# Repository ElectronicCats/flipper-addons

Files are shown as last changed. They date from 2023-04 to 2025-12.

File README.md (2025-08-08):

# Electronic Cats Flipper Add-Ons 😼 :dolphin: 

This repository contains a collection of our Add-Ons for Flipper, the open-source hardware platform for hacking and security research.

<a href="https://github.com/ElectronicCats/flipper-addons/wiki">
  
  
</a>

<p align=center>
<a href="https://electroniccats.com/?s=flipper&post_type=product&product_cat=">
  
</a>
<a href="https://github.com/ElectronicCats/flipper-addons/wiki">
  
</a>
</p>

<p align=center>
    Also available at distributors:
  </p>
<p align=center>
  <a href="https://labs.ksec.co.uk/product-category/electronic-cat/">
    
  </a>
</p>

## Working
- Marauder Magspoof
- Marauder
- SubGHz LoRa ([**Flipper LoRa Relay App**](https://github.com/ElectronicCats/flipper-SX1262-LoRa))
- MagSpoof
- Modbus ([**Flipper RS485 ModBus App**](https://github.com/ElectronicCats/flipper-rs485modbus))
- CANBus ([**Flipper CANBUS App**](https://github.com/ElectronicCats/flipper-MCP2515-CANBUS))
- Ethernet ([**Flipper ENC28J60 Ethernet App**](https://github.com/ElectronicCats/flipper-ENC28J60-ethernet))
  
 ## Prototypes
- UWB

## How to contribute 
 Contributions are welcome! 

Please read the document [**Contribution Manual**](https://github.com/ElectronicCats/electroniccats-cla/blob/main/electroniccats-contribution-manual.md)  which will show you how to contribute your changes to the project.

✨ Thanks to all our [contributors](https://github.com/ElectronicCats/flipper-addons/graphs/contributors)! ✨

See [**_Electronic Cats CLA_**](https://github.com/ElectronicCats/electroniccats-cla/blob/main/electroniccats-cla.md) for more information.

See the  [**community code of conduct**](https://github.com/ElectronicCats/electroniccats-cla/blob/main/electroniccats-community-code-of-conduct.md) for a vision of the community we want to build and what we expect from it.

## Maintainer

<p align=center>
<a href="https://github.com/sponsors/ElectronicCats">
  
</a>
</p>

Electronic Cats invests time and resources providing this open-source design, please support Electronic Cats and open-source hardware by purchasing products from Electronic Cats!

## License

<a
href="https://github.com/ElectronicCats">



</a>

Designed by Electronic Cats.

Firmware released under an GNU AGPL v3.0 license. See the LICENSE file for more information.

Hardware released under an CERN Open Hardware Licence v1.2. See the LICENSE_HARDWARE file for more information.

Electronic Cats is a registered trademark, please do not use if you sell these PCBs.

Jul 2022

[Agregando el link como referencia]: <https://github.com/ElectronicCats/Template-Project-KiCAD-CI>

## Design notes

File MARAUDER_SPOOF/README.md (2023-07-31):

# Marauder Spoof
It is the mix of our famous Magspoof version with an ESP32S3 module loaded with Marauder A suite of WiFi/Bluetooth offensive and defensive tools for the ESP32

This addon adds the function of the famous Magspoof to Flipper, we use the same components and improvements that have our versions of magspoof, now adapted to Flipper. 

## How does MagSpoof work?
- Allows you to store all of your credit cards and magstripes in one device
- Works on traditional magstripe readers wirelessly (no NFC/RFID required)
- Can disable Chip-and-PIN (code not included)
- Correctly predicts Amex credit card numbers + expirations from previous card number (code not included)
- Supports all three magnetic stripe tracks, and even supports Track 1+2 simultaneously
- Easy to build using Arduino or other common parts
- MagSpoof can be used as a traditional credit card and simply store all of your credit cards (and with modification, can technically disable chip requirements) in various impressive and exciting form factors, or can be used for security research in any area that would traditionally require a magstripe, such as readers for credit cards, drivers licenses, hotel room keys, automated parking lot tickets, etc.

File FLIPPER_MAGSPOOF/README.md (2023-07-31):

# Flipper Magspoof
This addon adds the function of the famous Magspoof to Flipper, we use the same components and improvements that have our versions of magspoof, now adapted to Flipper. 

Flipper Magspoof is a device that can spoof/emulate any magnetic stripe or credit card. It can work “wirelessly”, even on standard magstripe/credit card readers, by generating a strong electromagnetic field that emulates a traditional magnetic stripe card.

### How does MagSpoof work?
- Allows you to store all of your credit cards and magstripes in one device
- Works on traditional magstripe readers wirelessly (no NFC/RFID required)
- Can disable Chip-and-PIN (code not included)
- Correctly predicts Amex credit card numbers + expirations from previous card number (code not included)
- Supports all three magnetic stripe tracks, and even supports Track 1+2 simultaneously
- Easy to build using Arduino or other common parts
- MagSpoof can be used as a traditional credit card and simply store all of your credit cards (and with modification, can technically disable chip requirements) in various impressive and exciting form factors, or can be used for security research in any area that would traditionally require a magstripe, such as readers for credit cards, drivers licenses, hotel room keys, automated parking lot tickets, etc.

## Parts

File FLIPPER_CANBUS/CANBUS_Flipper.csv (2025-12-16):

Value | Reference | Footprint | LCSC# | Qty | DNP | manf#
10uF | C1,C9,C10 | Capacitor_SMD:C_0603_1608Metric | C19702 | 3
18pF | C2,C3 | Capacitor_SMD:C_0603_1608Metric | C5137620 | 2
0.1uF | C4,C5,C11 | Capacitor_SMD:C_0603_1608Metric | C14663 | 3
4.7nF | C6 | Capacitor_SMD:C_0603_1608Metric | C85980 | 1
47pF | C7,C8 | Capacitor_SMD:C_0603_1608Metric | C5137501 | 2
MMBZ27VCL-7-F | D1,D2 | Package_TO_SOT_SMD:SOT-23 | C698227 | 2
Conn_01x08_Socket | J1 | Connector_PinHeader_2.54mm:PinHeader_1x08_P2.54mm_Vertical | C7501586 | 1
Conn_01x10_Socket | J2 | Connector_PinHeader_2.54mm:PinHeader_1x10_P2.54mm_Vertical | C7430366 | 1
Conn | J3 | TerminalBlock:TerminalBlock_bornier-2_P5.08mm |  | 1 |  | TRT-02
STBY SEL | JP1 | Footprints:Jumper | C163836 | 1
STBY | JP2 | Footprints:Jumper | C163836 | 1
Jumper_2_Open | JP3 | Jumper:SolderJumper-2_P1.3mm_Open_Pad1.0x1.5mm |  | 1 | DNP
10K | R1 | Resistor_SMD:R_0603_1608Metric | C217281 | 1
60.2 | R2,R5 | Resistor_SMD:R_0603_1608Metric | C2086358 | 2
MCP251863T-H-SS | U3 | Package_SO:SSOP-28_5.3x10.2mm_P0.65mm | C5226885 | 1
40MHz | Y1 | Crystal:Crystal_SMD_EuroQuartz_MT-4Pin_3.2x2.5mm | C1985459 | 1

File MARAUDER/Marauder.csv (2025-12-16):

Reference | Qty | Value | DNP | Footprint | Datasheet | LCSC# | manf#
C1,C2 | 2 | 10uF |  | Capacitor_SMD:C_0603_1608Metric |  | C85713
C3,C4,C5 | 3 | 100nF |  | Capacitor_SMD:C_0603_1608Metric |  | C597251
J1 | 1 | Conn_01x08_Socket |  | Connector_PinHeader_2.54mm:PinHeader_1x08_P2.54mm_Vertical | ~ | C492407
J2 | 1 | Conn_01x08_Socket | DNP | Connector_PinHeader_2.54mm:PinHeader_1x08_P2.54mm_Vertical | ~ | C492407
J3 | 1 | Conn_01x10_Socket |  | Connector_PinHeader_2.54mm:PinHeader_1x10_P2.54mm_Vertical | ~ | C57369
J4 | 1 | GPS | DNP | Connector_PinHeader_2.54mm:PinHeader_1x05_P2.54mm_Vertical | ~
J5 | 1 | Conn_01x10_Socket | DNP | Connector_PinHeader_2.54mm:PinHeader_1x10_P2.54mm_Vertical | ~ | C57369
P1 | 1 | USB_C_Plug_USB2.0 |  | Connectors:C393939 | https://datasheet.lcsc.com/lcsc/2108132030_Korean-Hroparts-Elec-TYPE-C-31-M-31_C2760486.pdf | C2760486
Q1,Q2 | 2 | DMP2004TK-7 |  | Package_TO_SOT_SMD:SOT-523 | ~ |  | DMP2004TK-7
R1,R2,R7 | 3 | 10K |  | Resistor_SMD:R_0603_1608Metric |  | C217281
R3,R4 | 2 | 5k1 |  | Resistor_SMD:R_0603_1608Metric | https://datasheet.lcsc.com/lcsc/1810170519_PANASONIC-ERJ3RBD5101V_C191782.pdf | C156350
R6 | 1 | 150 |  | Resistor_SMD:R_0603_1608Metric | ~ | C2692872
R8,R9 | 2 | 4k7 |  | Resistor_SMD:R_0603_1608Metric | ~ | C394547
SW1 | 1 | RESET |  | Button_Switch_SMD:SW_SPST_TL3342 | https://datasheet.lcsc.com/lcsc/2205161616_E-Switch-TL3342F450QG_C2886897.pdf | C2886897 | TL3342F450QG
SW2 | 1 | GPIO |  | Button_Switch_SMD:SW_SPST_TL3342 | https://datasheet.lcsc.com/lcsc/2205161616_E-Switch-TL3342F450QG_C2886897.pdf | C2886897 | TL3342F450QG
U1 | 1 | ESP32-C5-WROOM-1-N4 |  | Marauder:XCVR_ESP32-C5-WROOM-1U-N8R8 |  |  | 356-ESP32C5WROM1N4

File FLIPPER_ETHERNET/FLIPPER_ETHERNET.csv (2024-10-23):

Reference | Value | Datasheet | Footprint | Qty | DNP | #LSCS | Proveedor | manf#
C1,C5 | 18pF |  | Capacitor_SMD:C_0603_1608Metric | 2 |  | C107040 | LCSC | CC0603JRNPO9BN180
C2 | 10uF |  | Capacitor_SMD:C_0603_1608Metric | 1 |  | C1691 | LCSC | CL10A106MQ8NNNC
C3,C4,C6,C7,C8,C9,C10 | 0.1uF | ~ | Capacitor_SMD:C_0603_1608Metric | 7 |  | C14663 | LCSC | CC0603KRX7R9BB104
FB1 | FerriteBead 80 mA | https://www.lcsc.com/datasheet/lcsc_datasheet_2312131724_Vishay-Intertech-ILBB0805ER202V_C6639322.pdf | FLIPPER_ETHERNET:BLM18SP221SN1B | 1 |  | C85824 | LCSC | BLM18AG102SN1D
J1 | RJ45_Hanrun_HR911105A_Horizontal | https://www.lcsc.com/datasheet/lcsc_datasheet_1811141815_HANRUN-Zhongshan-HanRun-Elec-HR911105A_C12074.pdf | Connector_RJ:RJ45_Hanrun_HR911105A_Horizontal | 1 |  | C12074 | LCSC | HR911105A
J2 | Conn_01x08_Socket | ~ | Connector_PinHeader_2.54mm:PinHeader_1x08_P2.54mm_Vertical | 1 |  | C7501586 | LCSC | PH2.54-01-08PZD
J3 | Conn_01x10_Socket | ~ | Connector_PinHeader_2.54mm:PinHeader_1x10_P2.54mm_Vertical | 1 |  | C7501587 | LCSC | PH2.54-01-10PZD
R1 | 100R | ~ | Resistor_SMD:R_0603_1608Metric | 1 |  | C22775 | LCSC | 0603WAF1000T5E
R2 | 10K | ~ | Resistor_SMD:R_0603_1608Metric | 1 |  | C2930027 | LCSC | FRC0603J103TS
R5,R6,R7,R8 | 49.9R |  | Resistor_SMD:R_0603_1608Metric | 4 |  | C23185 | LCSC | 0603WAF499JT5E
R9 | 2.32K |  | Resistor_SMD:R_0603_1608Metric | 1 |  | C2933173 | LCSC | FRC0603F2321TS
R12,R13 | 51R | ~ | Resistor_SMD:R_0603_1608Metric | 2 |  | C23197 | LCSC | 0603WAF510JT5E
SW1 | SW_Push | ~ | Button_Switch_SMD:SW_Push_1P1T_XKB_TS-1187A | 1 |  | C2886897 | LCSC | TS-1187A-C-C-B
U1 | ENC28J60x-ML | https://ww1.microchip.com/downloads/aemDocuments/documents/OTH/ProductDocuments/DataSheets/39662e.pdf | Package_DFN_QFN:QFN-28-1EP_6x6mm_P0.65mm_EP4.25x4.25mm | 1 |  | C57281 | Mouser | ENC28J60-I/ML
Y1 | 25MHz | https://www.lcsc.com/datasheet/lcsc_datasheet_2304140030_JGHC-S2125000101080_C390792.pdf | Crystal:Crystal_SMD_SeikoEpson_FA128-4Pin_2.0x1.6mm | 1 |  | C390792 | LCSC | S2125000101080

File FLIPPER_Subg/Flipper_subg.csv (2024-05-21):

# | Reference | Qty | Value | Footprint | DNP | LCSC# | manf#
1 | AE1, AE2 | 2 | Antenna | RF_Antenna:Texas_SWRA416_868MHz_915MHz | DNP | - | -
2 | AE3 | 1 | Antenna_Shield | subg:CONN1_U.FL-R-SMT-180_HIR |  | C411563
3 | AE4 | 1 | u.fl | subg:CONN1_U.FL-R-SMT-180_HIR |  | C411563
4 | C1, C2, C5, C8, C9, C10 | 6 | 0.1uF | Capacitor_SMD:C_0603_1608Metric |  | C14663 | CC0603KRX7R9BB104
5 | C3, C6 | 2 | 27pF | Capacitor_SMD:C_0603_1608Metric |  | C92670 | 0603YA270KAT2A
6 | C4 | 1 | 470nF | Capacitor_SMD:C_0603_1608Metric |  | C170149 | CL10A474KB8NNNC
7 | C7 | 1 | 47pF | Capacitor_SMD:C_0603_1608Metric |  | C519486 | CC0603FRNPO9BN470
8 | C11 | 1 | 10uF | Capacitor_SMD:C_0603_1608Metric |  | C85713
9 | C12, C14 | 2 | 1nF | Capacitor_SMD:C_0603_1608Metric |  | C1588 | CL10B102KB8NNNC
10 | C13 | 1 | 100pF | Capacitor_SMD:C_0603_1608Metric |  | C14858 | CL10C101JB8NNNC
11 | C15, C16 | 2 | 3.3pF | Capacitor_SMD:C_0603_1608Metric |  | C2909455
12 | D1 | 1 | LED | LED_SMD:LED_0805_2012Metric |  | C205442 | ORH-G35A
13 | J1 | 1 | Conn_01x10_Socket | Connector_PinHeader_2.54mm:PinHeader_1x10_P2.54mm_Vertical |  | C492418
14 | J2 | 1 | Conn_01x08_Socket | Connector_PinHeader_2.54mm:PinHeader_1x08_P2.54mm_Vertical |  | C2894950
15 | L1 | 1 | 15uH | Inductor_SMD:L_0603_1608Metric |  | C57838 | SDFL1608T150KTF
16 | L2 | 1 | 47nH | Inductor_SMD:L_0603_1608Metric |  | C29683 | SCHF160808H47NJT
17 | L3 | 1 | 9.1nH | Inductor_SMD:L_0603_1608Metric |  | C395094 | VHF160808H9N1JT
18 | R1 | 1 | 56K | Resistor_SMD:R_0603_1608Metric |  | C2828642
19 | R2, R4 | 2 | 100R | Resistor_SMD:R_0603_1608Metric |  | C700506 | RT0603DRD07100RL
20 | R3 | 1 | 1K | Resistor_SMD:R_0805_2012Metric |  | C25623 | 0805W8J0102T5E
21 | R5, R7 | 2 | 0 | Resistor_SMD:R_0402_1005Metric |  | C140225
22 | R6, R8 | 2 | 0 | Resistor_SMD:R_0402_1005Metric | DNP | C140225
23 | U1 | 1 | SX1262IMLTRT | Package_DFN_QFN:QFN-24-1EP_4x4mm_P0.5mm_EP2.65x2.65mm |  | C191341
24 | U2 | 1 | CC1101RGPR | Package_DFN_QFN:QFN-20-1EP_4x4mm_P0.5mm_EP2.5x2.5mm_ThermalVias |  | C29953
25 | U3 | 1 | 0900FM15D0039 | subg:0900FM15D0039E |  |  | 0900FM15D0039E
26 | U4 | 1 | 0915BM15A0001E | subg:0915BM15A0001E |  |  | 0915BM15A0001E
27 | U5 | 1 | PE42421 | Package_TO_SOT_SMD:SOT-363_SC-70-6 |  |  | PE42421SCAA-Z
28 | Y1 | 1 | 32Mhz | Crystal:Crystal_SMD_2520-4Pin_2.5x2.0mm |  | C255969 | Q24FA20H0021700
29 | Y2 | 1 | 26Mhz | Crystal:Crystal_SMD_2520-4Pin_2.5x2.0mm |  |  | ECS-260-8-36-CKY-TR

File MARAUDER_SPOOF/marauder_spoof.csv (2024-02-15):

Reference | Value | Footprint | Datasheet | LCSC# | manf# | provedor | Qty
C1 | 1uF | Capacitor_SMD:C_0603_1608Metric | https://datasheet.lcsc.com/lcsc/1912111437_CCTC-TCC0603COG100J500CT_C376764.pdf | C15849 |  | LCSC | 1
C2-C4 | 10uF | Capacitor_SMD:C_0603_1608Metric | https://datasheet.lcsc.com/lcsc/1912111437_CCTC-TCC0603COG100J500CT_C376764.pdf | C85713 |  | LCSC | 3
J1 | Coil | Connector_PinHeader_2.54mm:PinHeader_1x02_P2.54mm_Vertical | ~ |  | WR301025-19M8-G |  | 1
J2 | Conn_01x10_Socket | Connector_PinHeader_2.54mm:PinHeader_1x10_P2.54mm_Vertical | ~ | C57369 |  |  | 1
J3 | Conn_01x08_Socket | Connector_PinHeader_2.54mm:PinHeader_1x08_P2.54mm_Vertical | ~ | C492407 |  |  | 1
J6 | GPS | Connector_PinHeader_2.54mm:PinHeader_1x05_P2.54mm_Vertical | ~ |  |  |  | 1
P1 | USB_C_Plug_USB2.0 | Connectors:C393939 | https://datasheet.lcsc.com/lcsc/2108132030_Korean-Hroparts-Elec-TYPE-C-31-M-31_C2760486.pdf | C2760486 |  | LCSC | 1
Q1, Q2 | DMP2004TK-7 | Package_TO_SOT_SMD:SOT-523 | ~ |  | DMP2004TK-7 | MOUSER | 2
R1, R2, R5, R6 | 10K | Resistor_SMD:R_0603_1608Metric | -- mixed values -- | C2930027 |  | LCSC | 4
R3, R4 | 5k1 | Resistor_SMD:R_0603_1608Metric | https://datasheet.lcsc.com/lcsc/1810170519_PANASONIC-ERJ3RBD5101V_C191782.pdf | C156350 |  | LCSC | 2
R7 | 150 | Resistor_SMD:R_0603_1608Metric | ~ | C2692872 |  | LCSC | 1
R8, R9 | 4k7 | Resistor_SMD:R_0603_1608Metric | ~ | C394547 |  | LCSC | 2
SW1 | RESET | Button_Switch_SMD:SW_SPST_TL3342 | https://datasheet.lcsc.com/lcsc/2205161616_E-Switch-TL3342F450QG_C2886897.pdf |  | TL3342F450QG | LCSC | 1
SW2 | GPIO | Button_Switch_SMD:SW_SPST_TL3342 | https://datasheet.lcsc.com/lcsc/2205161616_E-Switch-TL3342F450QG_C2886897.pdf |  | TL3342F450QG | LCSC | 1
U1 | TC4424 | Package_SO:SOIC-8_3.9x4.9mm_P1.27mm | https://www.mouser.mx/datasheet/2/268/21998b-53545.pdf | C44150 |  |  | 1
U2 | ESP32-S3-WROOM-1U-N4 | RF_Module:ESP32-S3-WROOM-1U | https://www.espressif.com/sites/default/files/documentation/esp32-s3-wroom-1_wroom-1u_datasheet_en.pdf |  | ESP32-S3-WROOM-1U-N4 | MOUSER | 1

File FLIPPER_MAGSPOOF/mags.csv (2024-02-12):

# | Reference | Qty | Value | Footprint | DNP | LCSC# | manf#
1 | J1 | 1 | Coil | Connector_PinHeader_2.54mm:PinHeader_1x02_P2.54mm_Vertical |  |  | WMRR138F-0
2 | J2 | 1 | Conn_01x10_Socket | Connector_PinHeader_2.54mm:PinHeader_1x10_P2.54mm_Horizontal |  | C57369
3 | J3 | 1 | Conn_01x08_Socket | Connector_PinHeader_2.54mm:PinHeader_1x08_P2.54mm_Horizontal |  | C492407
4 | J4 | 1 | Conn_01x08_Socket | Connector_PinHeader_2.54mm:PinHeader_1x08_P2.54mm_Vertical | DNP | C492407
5 | J5 | 1 | Conn_01x10_Socket | Connector_PinHeader_2.54mm:PinHeader_1x10_P2.54mm_Vertical | DNP | C57369
6 | SW1 | 1 | On | footprintsg:JS102011SAQN |  |  | JS102011SAQN
7 | U1 | 1 | TC4424 | Package_SO:SOIC-8_3.9x4.9mm_P1.27mm |  | C44150 | TC4424AVOA713

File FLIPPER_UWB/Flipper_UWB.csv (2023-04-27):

# | Reference | Qty | Value | Footprint | DNP | LCSC# | manf#
1 | C1 | 1 | 100uF | Capacitor_SMD:C_0805_2012Metric |  |  | 581-TLCR107M006RTA
2 | D1, D2 | 2 | LED | LED_SMD:LED_0805_2012Metric |  | C205442 | ORH-G35A
3 | D3 | 1 | LED | LED_SMD:LED_0805_2012Metric |  | C84261 | NCD0805Y1
4 | D4 | 1 | LED | LED_SMD:LED_0805_2012Metric |  | C130114 | D-R080508L3-KS2
5 | IC1 | 1 | DWM1000 | RF_Module:DWM1000 |  |  | 772-DWM1000
6 | J1 | 1 | Conn_01x08_Socket | Connector_PinHeader_2.54mm:PinHeader_1x08_P2.54mm_Horizontal |  | C5360907 | PZ2.54-1*20-WZ
7 | J2 | 1 | Conn_01x10_Socket | Connector_PinHeader_2.54mm:PinHeader_1x10_P2.54mm_Horizontal |  | C5360907 | PZ2.54-1*20-WZ
8 | R1, R2, R3, R4, R5 | 5 | 1K | Resistor_SMD:R_0805_2012Metric |  | C25623 | 0805W8J0102T5E

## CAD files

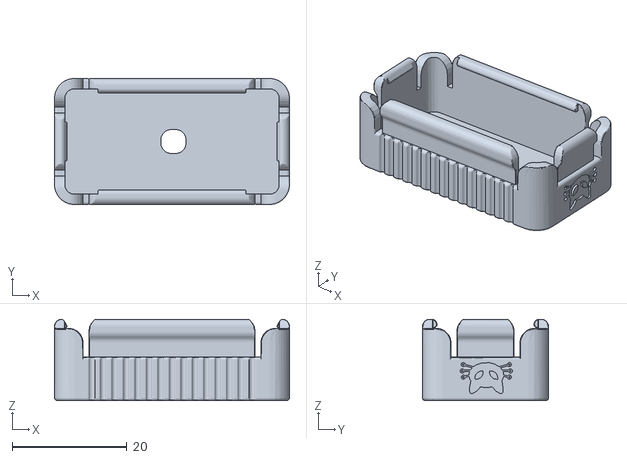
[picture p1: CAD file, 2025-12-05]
CASES/FLIPPER_CANBUS/OBD-PLUG-EC.stl
41.0 x 22.0 x 14.2

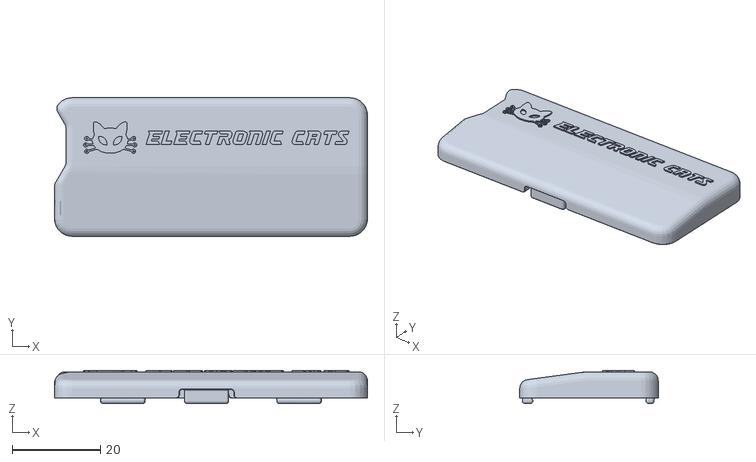
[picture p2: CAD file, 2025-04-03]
CASES/FLIPPER_MAGSPOOF/PART A-FLIPPER MAGSPOOF CASE.stl
71.0 x 31.5 x 7.50

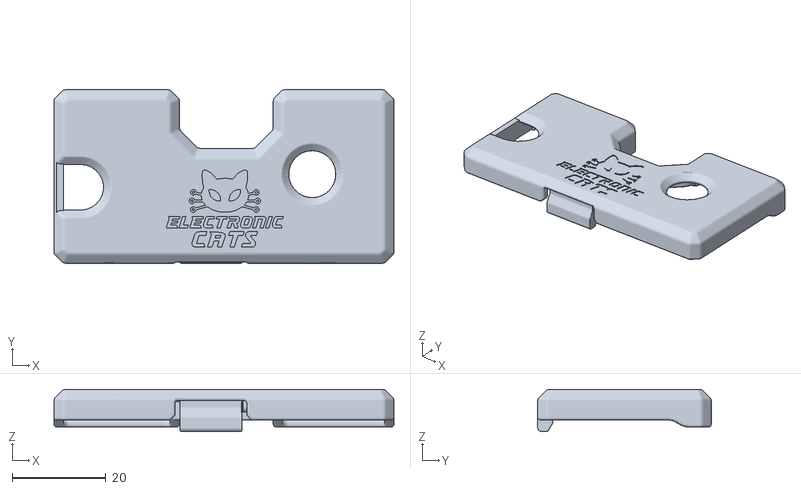
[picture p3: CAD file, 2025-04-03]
CASES/FLIPPER_Subg/SUBGHZ_CASE.stl
72.5 x 37.0 x 9.00

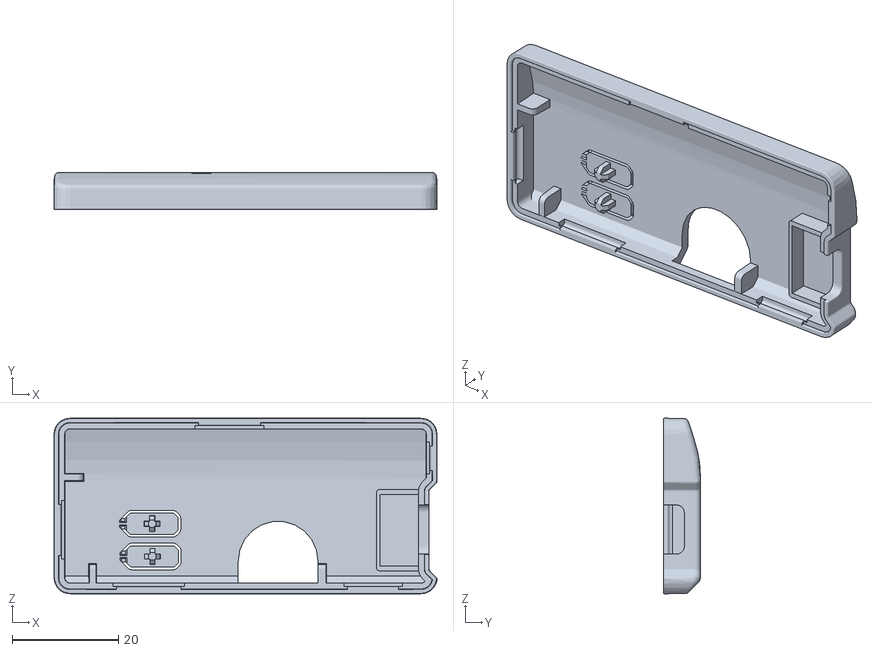
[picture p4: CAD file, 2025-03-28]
CASES/MARAUDER/PART_A-MARAUDER_CASE.stl
72.0 x 7.00 x 33.0

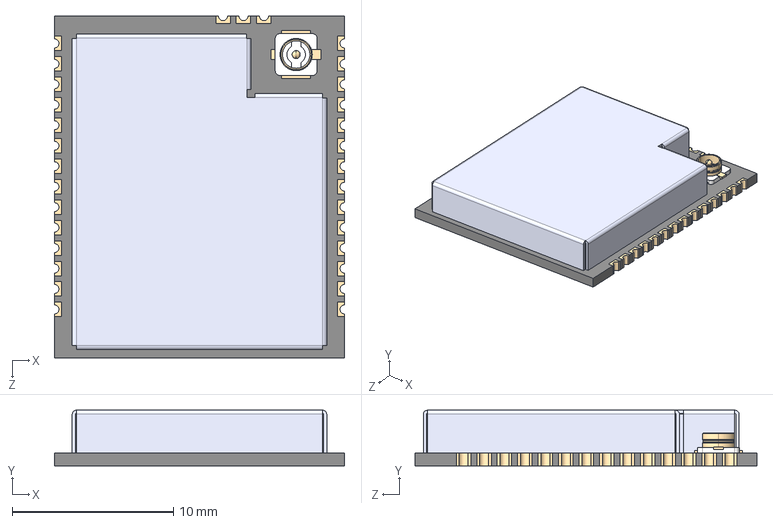
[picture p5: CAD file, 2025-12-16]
MARAUDER/3D/ESP32-C5-WROOM-1U-N8R8.step
18.0 x 3.45 x 21.2 mm

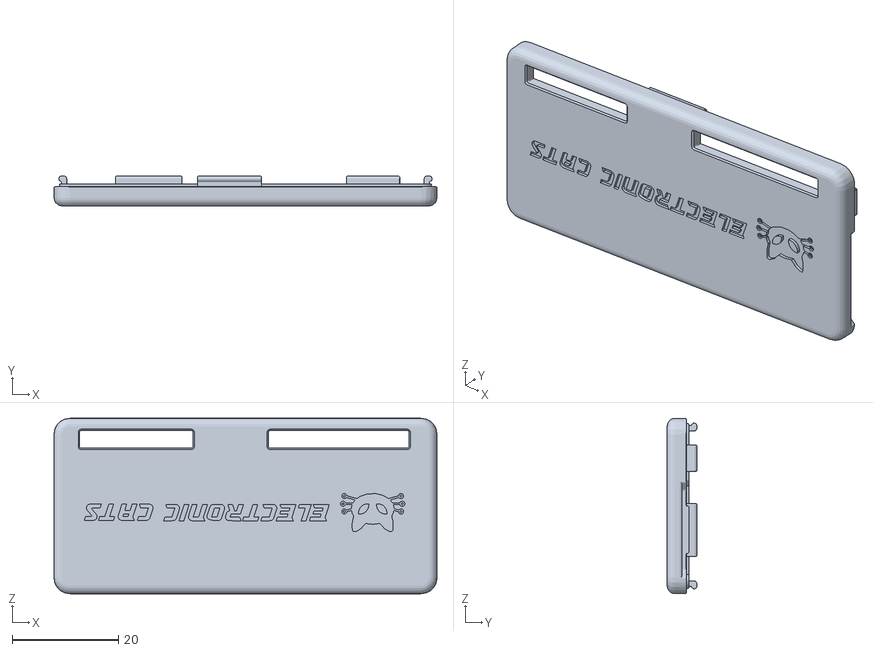
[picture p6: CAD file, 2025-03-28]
CASES/MARAUDER/PART_B-MARAUDER_CASE.stl
72.0 x 5.60 x 33.0

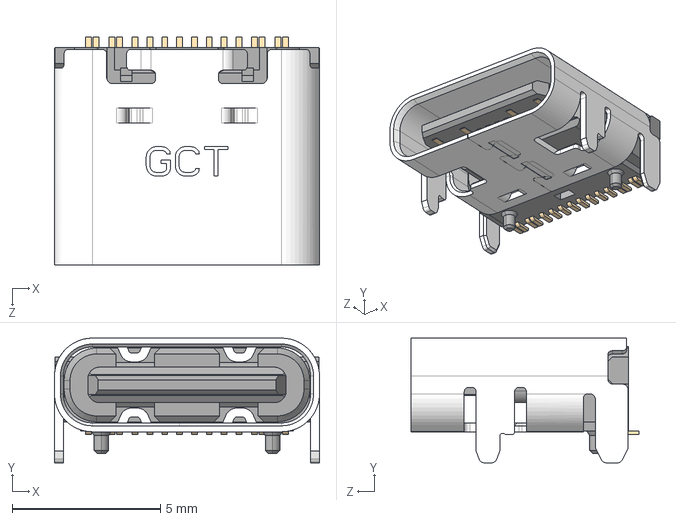
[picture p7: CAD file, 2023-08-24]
MARAUDER/3D/USB4105-GF-A.stp
8.94 x 4.21 x 7.70 mm
HSG_默认

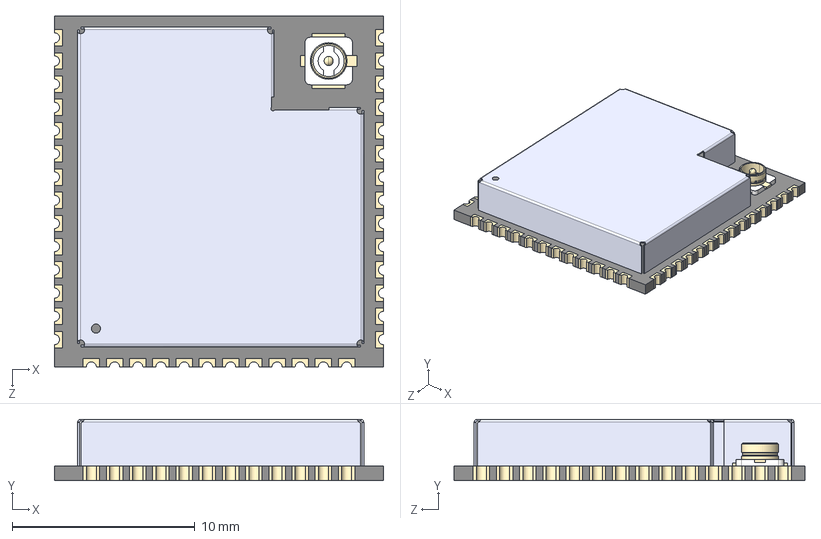
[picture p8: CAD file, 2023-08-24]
MARAUDER/3D/ESP32-S3-WROOM-1U-N16--3DModel-STEP-56544.STEP
18.0 x 3.35 x 19.2 mm

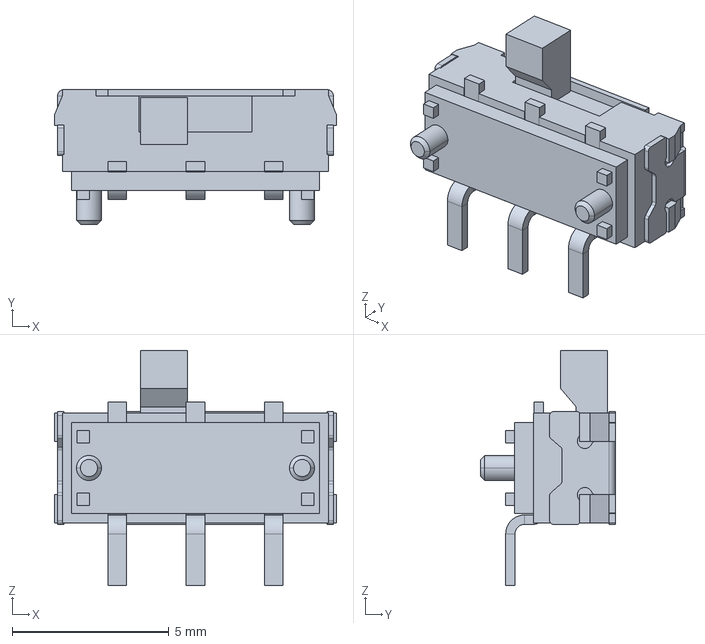
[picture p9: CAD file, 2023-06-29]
footprintsg/3D/JS102011SAQN--3DModel-Eagle-1.STEP
9.00 x 4.30 x 7.50 mm

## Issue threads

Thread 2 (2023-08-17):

3D case for the MARAUDER_SPOOF

Gino-Tonic, 2023-08-17:
Hi

I have designed a 3D case for the MARAUDER_SPOOF - if you want to add it to your repository...

Thanks for a great device!

[3D_case_Marauder_spoof.zip](https://github.com/ElectronicCats/flipper-shields/files/12371008/3D_case_Marauder_spoof.zip)

Gino-Tonic, 2023-08-18:
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

xpeqex, 2023-08-18:
@Gino-Tonic

Excellent implementation, thank you for sharing the picture!

We will have to print some at the office and test the add-on along with the case.

Thank you for your support and your time for sharing this with us.

Feel free to reach out to us again in case you have any queries!

xpeqex, 2023-08-25:
Hi @Gino-Tonic

I'm glad to inform you that we have added a link to this issue in the [Marauder Spoof wiki](https://github.com/ElectronicCats/flipper-shields/wiki/Flipper-Add-On:-Marauder-Spoof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), so the community can download and print your 3D design.

Closed 2023-08-17.

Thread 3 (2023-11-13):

All .pcap files have 0 bytes on flipper's SD card

b1scoito, 2023-11-13:
Hello, I've been trying to make .pcap files writing work with your guys board, but to no success, the onboard ESP32-S3-WROOM-1U doesn't come with a SD card slot and serial communication between ESP32Marauder and the Flipper Zero doesn't appear to work, Wi-Fi Marauder GPIO app only writes 0 bytes .pcap files, does the board support writing through serial, or is there any custom firmware for the Electronic Cats board, I've actually not tested the firmware that came with the board since I wanted to update to the latest ESP32Marauder as soon as possible. Have you guys tested the .pcap writing functionality under Apps -> GPIO -> [ESP32] Wi-Fi Marauder -> Sniff [raw]? For me the file gets written in /apps_data/marauder/pcaps with 0 bytes.

I'm running on latest ESP32Marauder with the MultiboardS3 firmware, flashed through FZEasyMarauderFlash that uses esptool since I can't make the ESP32-S3 enter reflash mode, I've tried tons of methods, even the common one, hold the boot button, click the reset button, and release the boot button, nothing works. The `ESP Flasher` Flipper Zero app depends on this functionality to flash a firmware directly through Flipper.

TL;DR, I was able to successfully flash new firmware into your guys's board through esptool, but not through either the esp.huhn.me website or the `ESP Flasher` Flipper app, however, the Multiboard S3 firmware doesn't appear to have serial communication between flipper's SD card and the ESP32-S3 board, thus, not successfully writing .pcap files from sniffing network packets.

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

xpeqex, 2023-11-14:
@b1scoito
Thank you for reporting the issue with the .pcap files.

According to the reports created in the[ justcallmekoko/ESP32Marauder](https://github.com/justcallmekoko/ESP32Marauder) repository, there is a firmware issue that prevents the ESP32 module from communicating with the flipper via UART. This results in the issue that you have reported.

Other Marauder users, regardless of the board, have experienced this error and have shared some of their solutions at the following link:

https://github.com/justcallmekoko/ESP32Marauder/issues/249

Unfortunately, the solutions presented in this link are only functional for ESP32-S2 modules. In these cases, the port of the ESP32-S2 module has been changed to resolve the error.

Our Flipper Addon Marauder includes an ESP32-S3, so it is not compatible with this solution. I have tried this on my own and it does not work.

Here is an issue related to this issue an ESP32-S3 modules: https://github.com/justcallmekoko/ESP32Marauder/issues/370

Because this issue is directly related to the firmware, which is external, we cannot do much more than wait for the firmware developers to find a solution and add ESP32-S3 module compatibility to change its port and thus resolve the issue that .pcap files are not saving any information.

Regarding how to put the module into boot/flash mode, I recommend referring to this section of our wiki:

- [Flipper AddOn: Marauder Spoof update the ESP32-S3 marauder firmware](https://github.com/ElectronicCats/flipper-shields/wiki/Flipper-Add%E2%80%90On:-Marauder-Spoof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)

I hope this information is helpful and we appreciate your understanding.

Greetings

b1scoito, 2023-11-15:
I've tried to edit the firmware to match the pins present in the board, and enabling the ENABLE_PACKETS_SERIAL macro, but wasn't able to successfully compile it, can I get in touch with you guys so we can take a look at it and create a separate fork for your guys's board?

xpeqex, 2023-11-17:
@b1scoito

It is nice to read you tried solving this.

Regarding the request to do a Marauder fork, we have plans to do it, modify the firmware, and make it compatible with the ESP32-S3 module since we noticed that the firmware is mainly focused on ESP32-S2 modules. There is no estimated time when we will do this, so we kindly recommend you keep posted here in GitHub and the wiki updates.

Additionally, I will keep track of the issue on the official Marauder repo in case there is any update.

xpeqex, 2023-11-21:
Hello @b1scoito

I am glad to let you know that our team worked on this and compiled a special firmware `.bin` file in order to make the UART communication work and now the pcaps files are not empty. You can find the file [here]( https://github.com/ElectronicCats/ESP32Marauder/blob/b6e1416794d4332923a48b3fb893e79b4a1a9e15/esp32_marauder/esp32_marauder.ino.esp32s3.bin).

Please perform the update for the ESP32-S3 module as usual following the [**Update the ESP32-S3** guide](https://github.com/ElectronicCats/flipper-shields/wiki/Flipper-Add%E2%80%90On:-Marauder-Spoof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) swapping the Firmware file with the mentioned on this message.

Let me know if that solves the issue!

xpeqex, 2023-11-22:
@b1scoito
No worries, we are also happy that is now working!

Feel free to reach out to us again. 😼

b1scoito, 2023-11-28:
Hello @sabas1080, I've been trying to compile the latest ESP32Marauder which adds support for selecting the HTML for Evil Portal through serial, I've managed to compile it successfully with all the changes in the `configs.h` file, but pcaps are being written still, with 0 bytes, of course, with your compiled firmware it works, but with mine which is just one version ahead of yours, doesn't.

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

b1scoito, 2023-11-28:
I'm interested in compiling it myself, which changes are needed to be made in the Arduino Core?

sabas1080, 2023-11-28:
I have uploaded the necessary changes, but still need to do some testing.

b1scoito, 2023-11-28:
I've tried setting the serial as shown on your commit: https://github.com/ElectronicCats/ESP32Marauder/commit/d40a452e608f7ec0953d48c42cc4eac72f838341 but still, to no success.

sabas1080, 2023-11-29:
can you write pcap files with information with the current changes from the last commit? I need to know what works for you with the latest changes.

xpeqex, 2023-11-29:
@b1scoito
I could not resist joining the conversation. Could you please let me know the saving path for the HTML file, so the Add-On can read it? 🐬

b1scoito, 2023-11-29:
> can you write pcap files with information with the current changes from the last commit? I need to know what works for you with the latest changes.

I haven't tried compiling your latest commit, but the first version you sent me worked with writing .pcap files.

b1scoito, 2023-11-29:
> @b1scoito I could not resist joining the conversation. Could you please let me know the saving path for the HTML file, so the Add-On can read it? 🐬

The Wi-FI Marauder updated so we can set the HTML file for Evil Portal through and it works flawlessly. After those changes some stuff changed in the code, but nothing I could see that affects the writing of .pcap files.

@sabas1080 Everything I did was getting the source-code from the latest v1.35.5 ESP32Marauder release and changing the macros in configs.h, and the serial pins, still, setting the HTML file for Evil Portal through serial works but not writing the buffer stream into .pcap files. What have you done in your first release to make it work?

sabas1080, 2023-11-29:
@b1scoito  I have only changed RX1 and TX1 to pins 17 and 18 according to our schematic, note that you must use the core version 2.0.11
https://github.com/espressif/arduino-esp32/blob/2.0.11/cores/esp32/HardwareSerial.cpp#L58

sabas1080, 2023-11-29:
@b1scoito Can you test the latest changes in the last commit? https://github.com/ElectronicCats/ESP32Marauder/commit/dcd55e64eb59fe133e635692eb9231adcc4cc120

b1scoito, 2023-11-29:
Ok. It worked, I see that in the commit before that one the RX and TX pins order is INVERTED! That made me so confused. Now that I'm using the esp32 core 2.0.11 (The ESP32Marauder tutorial says to install 2.0.10 so I had that one installed) and changed the order of the RX and TX pins it worked.

Should we PR to the original ESP32Marauder repository with a EC_SHIELD macro?

sabas1080, 2023-11-30:
looks good, it would be interesting

xpeqex, 2023-11-30:
@b1scoito

We would like to thank you for your comments and contributions to the Electronic Cats - Marauder community.

We are very happy that you have trusted us and are part of our community. Your report encouraged us to fix this, so the capabilities of Marauder Spoof Shield are now unleashed.

We hope that the Marauder team can take a look at your PR and add the Electronic Cats Marauder Add-On to the official repo. We will keep an eye on this.

Once again, we thank you for bringing this issue and your feedback to our attention. Please do not hesitate to contact us again if you have any questions or suggestions.
<p align=right>
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
</p>

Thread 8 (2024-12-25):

Any chance of getting your ESP32 Maurader board working with V1.2.0 of the marauder firmware?

avipars, 2024-12-25:
https://github.com/ElectronicCats/ESP32Marauder was built for a really old firmware, is there any chance of getting your board with the ESP32S3 working with a newer (official) version of ESP32Marauder?

sabas1080, 2025-03-11:
We are generating the binaries, in a few hours it will be ready. Welcome your feedback  https://github.com/ElectronicCats/ESP32Marauder/pull/2

Closed 2025-03-11.

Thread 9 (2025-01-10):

Flipper SubGhz - LoRA Addon -- Layout problem

beadon, 2025-01-10:
The space between the pads and trace is smaller than 0.12mm in one location.

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

In the layout for the board I see this:
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

and this

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

Here's the part datasheet

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

The part in the library is this :
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

Here is a fixed version:

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

beadon, 2025-01-10:
Fixed version - ( thanks to a friend, I can't take credit for this fix ).
[Flipper_subg-Gerber files-v2.zip](https://github.com/user-attachments/files/18371592/Flipper_subg-Gerber.files-v2.zip)

Repo owner, can you update the KiCAD files with this change ?

xpeqex, 2025-01-10:
Hi @beadon

Thank you for bringing this to our attention, we appreciate you had the time to check the design and correct it.

Would you mind doing a pull request with changes so we review it? You can find more information about how to contribute in our [Contribution Manual](https://github.com/ElectronicCats/electroniccats-cla/blob/main/electroniccats-contribution-manual.md)

beadon, 2025-01-12:
@xpeqex - I am having this created by PCBWay, and caught it when exporting the Gerbers.  I may have performed the export wrong for the manufacture, I was able to install PCBWay's new KiCAD plugin and it has exported what appears to be the correctly formatted Gerbers.  There may not need to be any changes done.

I will update you when they can confirm this next week.

xpeqex, 2025-01-13:
@beadon Thank you for the update. Just for your information, this has been passed to the engineering team, and they will work on this. As of now @Lizethgm will be following up.

Thank you!

beadon, 2025-01-14:
The board is successfully in manufacturing, and the issues are resolved that quoted above.  The short answer is watch the export from KiCAD carefully.  If you are using PCBWay, use their plugin to save yourself some time, and you can also export the same data and send to another manufacturer too using the plugin.

I will close this issue since this is not a problem with the source files.

Closed 2025-01-14.

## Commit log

2023-04-19 Schematic and PCB, shiel FlipperZero
    Schematic and PCB proposal for the UWB shield for FlipperZero
    [Flipper.kicad_pcb, Flipper.kicad_sch]
2023-04-20 Update Flipper PCB
    Update of the measurements between pins
    [Flipper.kicad_pcb]
2023-04-20 FLIPPER_UWB
    UWB shield update for FlipperZero
    [Flipper_UWB.kicad_pcb, Flipper_UWB.kicad_sch]
2023-04-21 Update Flipper_UWB pcb
    Corrected PCB
    [Flipper_UWB.kicad_pcb]
2023-04-24 Update and correction shield UWB
    Update and correction of the Flipper Zero UWB shield.
    [Flipper.kicad_pcb, Flipper.kicad_sch, Flipper_UWB.kicad_pcb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]
2023-04-24 FLIPPER_CAN_BUS
    Diseño de una trajeta externa para Flipper zero, siendo la funcionalidad de la tarjeta actuar como un CAN BUS
    [can bus.kicad_pcb, can bus.kicad_sch]
2023-04-24 FLIPPER_CAN_BUS
    Cambios en diseño
    [FLIPPER_CAN_BUS.kicad_pcb, FLIPPER_CAN_BUS.kicad_sch, can bus.kicad_pcb]
2023-04-24 got ignore update
    [FLIPPER_CAN_BUS.kicad_pcb, FLIPPER_CAN_BUS.kicad_sch]
2023-04-25 Correcion
    update
    [FLIPPER_CAN_BUS.kicad_pcb, FLIPPER_CAN_BUS.kicad_sch]
2023-04-25 upd PCB
    Correcion estetica
    [FLIPPER_CAN_BUS.kicad_pcb, FLIPPER_CAN_BUS.kicad_sch]
2023-04-25 upd
    Estetica
    [FLIPPER_CAN_BUS.kicad_sch]
2023-04-25 Correction shield FlipperZero UWB
    Correction of the PCB and schematic of the shield FlipperZero UWB
2023-04-25 Correction of the PCB and the schematic
    Correction of the PCB and the schematic of the UBW shield for the FlipperZero
    [Flipper_UWB.kicad_pcb, Flipper_UWB.kicad_sch]
2023-04-25 Correction
    FlipperZero CAN_BUS
    [FLIPPER_CAN_BUS.kicad_pcb]
2023-04-26 Update PCB FLipperZero UWB
    Update and correction PCB
    [Flipper_UWB.kicad_pcb]
2023-04-26 Update Flipper UWB
    Update Flipper UWB
    [Flipper_UWB.kicad_pcb]
2023-04-26 Update PCB UWB
    Update shield UWB
    [Flipper_UWB.kicad_pcb]
2023-04-26 Update UWB
    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
    [Flipper_UWB.kicad_pcb]
2023-04-27 upd
    CSV
    [FLIPPER_CAN_BUS.csv, FLIPPER_CAN_BUS.kicad_pcb]
2023-04-27 Update UWB
    Update PCB UWB
    [Flipper_UWB.kicad_pcb]
2023-04-27 Update PCB shield UWB
    Update PCB shield UWB
    [Flipper_UWB.kicad_pcb, Flipper_UWB.kicad_sch]
2023-04-27 BOM Flipper UWB
    [Flipper_UWB.csv]
2023-04-27 Update BOM shield UWB
    [Flipper_UWB.csv]
2023-04-27 upd
    upd bom
    [FLIPPER_CAN_BUS.csv, FLIPPER_CAN_BUS.kicad_pcb, FLIPPER_CAN_BUS.kicad_sch]
2023-04-28 Update shield UWB
    [Flipper_UWB.kicad_pcb, Flipper_UWB.kicad_sch]
2023-05-02 add magspoof pines
    [mags.kicad_pcb, mags.kicad_sch]
2023-05-02 add boom
    [mags.kicad_pcb, mags.kicad_sch]
2023-05-23 Fix Flipper_Magspoof
    [mags.kicad_pcb, mags.kicad_sch]
2023-05-23 fix dimensions Flipper_Magspoof
    [mags.kicad_pcb]
2023-05-23 add BOM and serigraphy
    [mags.kicad_pcb, mags.kicad_sch]
2023-05-23 Update BOM flipper_can_bus
    [FLIPPER_CAN_BUS.kicad_sch]
2023-05-24 Fix C1 part Flippper_can_bus
    [FLIPPER_CAN_BUS.kicad_sch]
2023-06-07 add version "v1.0"
    [mags.kicad_pcb]
2023-06-14 add logo EC
    [mags.kicad_pcb]
2023-06-29 add suubgig project
    [Flipper_subg.kicad_pcb, Flipper_subg.kicad_sch]
2023-06-29 marauder_spoof init
    [marauder_spoof.kicad_pcb, marauder_spoof.kicad_sch]
2023-06-30 update schematic subgig
    [Flipper_subg.kicad_pcb, Flipper_subg.kicad_sch]
2023-07-01 update layout
    [Flipper_subg.kicad_pcb, Flipper_subg.kicad_sch]
2023-07-01 update layout magspoof-wifi
    [marauder_spoof.kicad_pcb, marauder_spoof.kicad_sch]
2023-07-01 add 3D for esp32
    [marauder_spoof.kicad_pcb]
2023-07-01 modify version
    [marauder_spoof.kicad_pcb]
2023-07-07 update subgig BOM
    [Flipper_subg.kicad_sch]
2023-08-07 Enlarged U3 footprint
    [Flipper_subg.kicad_pcb]
2023-08-07 Board name and boot button label added in the marauder flipper
    [marauder_spoof.kicad_pcb]
2023-08-21 Starting the new flipper "Maraurder"
    [Marauder.kicad_pcb, Marauder.kicad_sch]
2023-08-22 Routing finished of flipper marauder
    [Marauder.kicad_pcb, Marauder.kicad_sch]
2023-08-22 BOM of flipper marauder generated
    [Marauder.csv, Marauder.kicad_sch]
2023-08-24 add 3d modules to flipper marauder.
    [ESP32-S3-WROOM-1U-N16--3DModel-STEP-56544.STEP, Marauder.kicad_pcb, USB4105-GF-A.stp]
2023-08-24 add silkscreen v1.1 to bottom view of flipper marauder
    [Marauder.kicad_pcb]
2023-09-19 New antenna added
    [Flipper_subg.csv, Flipper_subg.kicad_pcb, Flipper_subg.kicad_sch]
2023-09-19 Update labels
    [Flipper_subg.kicad_pcb]
2023-09-19 Tracks added to the antenna routing
    [Flipper_subg.kicad_pcb, Flipper_subg.kicad_sch]
2023-09-22 Update the antenna
    [Flipper_subg.kicad_pcb, Flipper_subg.kicad_sch]
2023-09-22 update u.fl connection
    [Flipper_subg.kicad_pcb, Flipper_subg.kicad_sch]
2023-09-22 BOM generated
    [Flipper_subg.csv, Flipper_subg.kicad_pcb, Flipper_subg.kicad_sch]
2023-09-25 add version at bottom of subGhz
    [Flipper_subg.kicad_pcb]
2024-01-10 Flippermagspoof.step and Flippersubg.step generated
    [Flipper_subg.kicad_pcb, mags.kicad_pcb]
2024-01-17 UPDATE FLIPPER MODBUS SHIELD
    [FLIPPER_MOD_BUS.kicad_pcb, FLIPPER_MOD_BUS.kicad_sch]
2024-01-22 Flipper_MOD_BUS RX TX Fixed
    [FLIPPER_MOD_BUS.kicad_pcb, FLIPPER_MOD_BUS.kicad_sch]
2024-01-23 Flipper Mod Bus Silkcscreen Updated
    [FLIPPER_MOD_BUS.kicad_pcb, FLIPPER_MOD_BUS.kicad_sch]
2024-01-24 Flipper MODBUS Back Silkscreen Updated
    [FLIPPER_MOD_BUS.kicad_pcb]
2024-01-24 init Flipper CanBus
    Replacement of Flipper Can_Bus
    [CANBUS_Flipper.kicad_pcb, CANBUS_Flipper.kicad_sch, FLIPPER_CAN_BUS.csv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]
2024-01-25 Flipper MODBUS Headers Updated
    [FLIPPER_MOD_BUS.kicad_pcb, FLIPPER_MOD_BUS.kicad_sch]
2024-01-29 Resistance Correction
    [CANBUS_Flipper.kicad_pcb, CANBUS_Flipper.kicad_sch]
2024-01-30 Add labels CANBUS
    [CANBUS_Flipper.kicad_pcb]
2024-02-12 BOM updated
    [Marauder.csv, Marauder.kicad_sch, mags.csv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]
2024-02-14 Marauder's BOM updated
    [Marauder.csv, Marauder.kicad_sch]
2024-02-15 MarauderSpoof's BOM updated
    [marauder_spoof.csv, marauder_spoof.kicad_sch]
2024-03-19 feat(hw):Canbus Shield jumper added
    [CANBUS_Flipper.kicad_pcb, CANBUS_Flipper.kicad_sch]
2024-03-20 feat(hw): Paths and jumper update
    [CANBUS_Flipper.kicad_pcb, CANBUS_Flipper.kicad_sch]
2024-03-20 feat(hw): update design
    [CANBUS_Flipper.kicad_pcb, CANBUS_Flipper.kicad_sch]
2024-03-21 feat(hw): jumper changed and bom added
    [CANBUS_Flipper.kicad_pcb, CANBUS_Flipper.kicad_sch, CANBUS_Flipper_BOM_V1.1.csv]
2024-03-21 feat(hw): add logo and Kicad8
    [CANBUS_Flipper.kicad_pcb]
2024-03-21 feat(hw): label updated
    [CANBUS_Flipper.kicad_pcb]
2024-03-22 fix(hw): DE RE Pull Down & Jumper
    [FLIPPER_MOD_BUS.kicad_pcb, FLIPPER_MOD_BUS.kicad_sch]
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2024-03-22 fix(hw): Jumpers & version Updated
    [FLIPPER_MOD_BUS.kicad_pcb, FLIPPER_MOD_BUS.kicad_sch]
2024-03-26 fix(hw): CANBUS shiled bom modified
    [CANBUS_Flipper.kicad_sch, CANBUS_Flipper_BOM_V1.1.csv]
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2024-04-11 fix(hw): Differential Pair
    [FLIPPER_MOD_BUS.kicad_pcb, FLIPPER_MOD_BUS.kicad_sch]
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2024-05-16 feat(hw): OBD2 connector files added
    [OBDII_connector.kicad_pcb, OBDII_connector.kicad_sch]
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2024-05-20 feat(Hw): add capacitor formosfet driver
    [mags.kicad_pcb, mags.kicad_sch]
2024-05-20 feat(Hw): change DNP for pre-manufacturing
    [CANBUS_Flipper.kicad_sch]
2024-05-21 fix: nets conflict solved & version label updated
    [FLIPPER_MOD_BUS.kicad_pcb]
2024-05-22 fix: DE & RE net corners fixed
    [FLIPPER_MOD_BUS.kicad_pcb]
2024-05-22 fix(hw): move J4 label
    [FLIPPER_MOD_BUS.kicad_pcb]
2024-06-17 feat: version Label got updated
    [CANBUS_Flipper.kicad_pcb, OBDII_connector.kicad_pcb]
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2024-06-17 fix(hw): update BOM, change comments to User Drawings
    [Flipper_subg.kicad_pcb, Flipper_subg.kicad_sch]
2024-06-19 feat: information about OBDII got updated
    [OBDII_connector.kicad_sch]
2024-06-19 feat: change shape of PCB & indicators added
    [OBDII_connector.kicad_pcb, OBDII_connector.kicad_sch]
2024-06-19 feat: position indicator added
    [OBDII_connector.kicad_pcb]
2024-06-19 fix: space between paths fixed
    [OBDII_connector.kicad_pcb]
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2024-07-31 feat: new dimensions added for OBDII connector
    [OBDII_connector.kicad_pcb, OBDII_connector.kicad_sch]
2024-07-31 feat: OBDII pcb design routed and labels got placed
    [OBDII_connector.kicad_pcb]
2024-08-01 fix (hw): update version label and change dimensions layer
    [mags.kicad_pcb]
2024-08-01 fix(fw): add thickness comment
    [mags.kicad_pcb]
2024-08-02 fix(hw): add thickness comment
    [marauder_spoof.kicad_pcb]
2024-08-19 fix: orientation of J3 footprint was wrong
    [CANBUS_Flipper.kicad_pcb, CANBUS_Flipper.kicad_sch]
2024-08-22 feat: change name addon
    [Flipper_subg.kicad_pcb]
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2024-08-22 fix: fix path
    [ESP32-S3-WROOM-1U-N16--3DModel-STEP-56544.STEP, Marauder.csv, Marauder.kicad_pcb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]
2024-09-03 feat (hw): remove DNP for J1 and J2
    [CANBUS_Flipper.kicad_sch]
2024-09-23 feat: FLIPPER_ETHERNET project uploaded
    [FLIPPER_ETHERNET.kicad_pcb, FLIPPER_ETHERNET.kicad_sch]
2024-09-26 feat: component reduction in the schematic of flipper ethernet and pcb first draft
    [FLIPPER_ETHERNET.kicad_pcb, FLIPPER_ETHERNET.kicad_sch]
2024-10-07 feat: second draft of flipper ethernet pcb
    [FLIPPER_ETHERNET.kicad_pcb, FLIPPER_ETHERNET.kicad_sch]
2024-10-09 feat: pcb corrected for possible first flipper ethernet prototype
    all 3d models added
    all labels added and reorganized
    button changed for smd metal button
    components reorganized
    leds deleted
    [FLIPPER_ETHERNET.kicad_pcb, FLIPPER_ETHERNET.kicad_sch]
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2024-10-09 feat: decoupling capacitors moved, labels modified
    [FLIPPER_ETHERNET.kicad_pcb]
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2024-10-11 feat: bom corrected and change of model components components changed were SW1 and FB1
    [FLIPPER_ETHERNET.csv, FLIPPER_ETHERNET.kicad_pcb, FLIPPER_ETHERNET.kicad_sch]
2024-10-14 fix (hw): remove DNP for J4
    [CANBUS_Flipper.kicad_sch]
2024-10-17 feat: flipper ethernet pcb adapted in olimex pcb
    All components passed behind the pcb except the
    RJ45 and reset button
    Decoupling capacitors of ENC28J60 added
    Crystal changed for a smaller one
    [FLIPPER_ETHERNET.kicad_pcb, FLIPPER_ETHERNET.kicad_sch]
2024-10-17 feat: some pcb routes corrected
    [FLIPPER_ETHERNET.kicad_pcb, FLIPPER_ETHERNET.kicad_sch]
2024-10-21 feat: flipper ethernet pcb modified
    decoupling capacitor connections fixed
    components moved close to the ethernet
    differential pairs and other routes modified
    [FLIPPER_ETHERNET.kicad_pcb, FLIPPER_ETHERNET.kicad_sch]
2024-10-21 fix traces
    [FLIPPER_ETHERNET.kicad_pcb]
2024-10-23 feat: Y1 updated in flipper ethernet bom
    [FLIPPER_ETHERNET.csv, FLIPPER_ETHERNET.kicad_pcb, FLIPPER_ETHERNET.kicad_sch]
2024-11-08 fix(hw): add DNP for J1 and J4 and update SW1,2 and Q1,2 mfr.#
    [marauder_spoof.kicad_sch]
2025-03-28 feat(hw): marauder case files
    [PART_A-MARAUDER_CASE.stl, PART_B-MARAUDER_CASE.stl]
2025-04-03 feat(hw): add board cases
    [CS6-SUBGHZ CASE.stl, CS7-PART A-FLIPPER MAGSPOOF CASE.stl]
2025-04-08 fix(hw): add gnd vias
    [marauder_spoof.kicad_pcb]
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2025-04-08 feat(hw): Update Marauder-Spoof version label
    [marauder_spoof.kicad_pcb]
2025-05-27 feat(Hw): changed reset to flipper
    [FLIPPER_ETHERNET.kicad_pcb, FLIPPER_ETHERNET.kicad_sch]
2025-12-05 feat(hw): OBD2 case 3D file
    [OBD-PLUG-EC.stl, PART A-FLIPPER MAGSPOOF CASE.stl, PART_A-MARAUDER_CASE.stl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]
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2026-05-07 feat: add GPS schematic
    [Marauder.kicad_sch]
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
